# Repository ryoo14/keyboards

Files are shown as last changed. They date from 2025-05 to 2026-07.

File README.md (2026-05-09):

# rhyn47

rhyn47 is a mechanical keyboard I designed.

It comes in three models: standard, low-profile and low-profile with trackball.

Please refer to the README file located in each keyboard's folder.

## Common Across All Models

- USB-C connectivity
- Direct-mounted RP2040 on the PCB
- 47-key ortholinear layout
- Hot-swapping switch support
- Screwless design
- Can be placed on top of a laptop (so-called “Sonshi style”)

## Standard

Standard

## Low-Profile

rhyl47

## Low-Profile with TrackBall

rhyn47-trackball

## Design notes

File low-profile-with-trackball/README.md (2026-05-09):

# rhyn47 low-profile with trackball

This is low-profile model of rhyn47 with trackball.

rhyn47-trackball

The case is the same as the [low-profile version](https://github.com/ryoo14/main/tree/rhyn47/low-profile).

It's a work in progress trackball case.

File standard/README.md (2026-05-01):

# rhyn47(Standard)

rhyn47

## Layout
https://www.keyboard-layout-editor.com/#/gists/312092b0a95833e6baeb8218b6a8bbec

## Features

### Key Layout
- **Ortholinear layout**: Clean, grid-based key arrangement
- **47-key configuration**: Compact design with 2U spacebar only option
- **Hot-swappable switches**: Compatible with hot-swap switch sockets only, allowing easy switch replacement
- **Minimal design**: No LEDs or additional features - focused on simplicity

### Design Philosophy
- **Laptop-friendly**: Designed for use on top of MacBooks and other laptops
- **Zero tilt**: No default inclination for comfortable laptop use
- **AirFeet compatible**: Built-in recesses on the bottom for Nuphy Air series AirFeet attachment
- **Shisou style typing**: Enables elevated typing position when AirFeet are installed
- **v0.3 screwless design**: Completely screwless assembly for easy maintenance and modification

## Build Guide
Please read the [article](https://ryoo.cc/blog/2025-06-20_intro_rhyn47). Since it is written in Japanese, please translate it.

## Information

### Manufacturing Notes
When ordering from JLC3DP:
- **Warning alerts**: Several warnings may appear during the ordering process
- **Warping concerns**: Engineers have raised concerns about significant warping when printing the case

When I placed my order, I received the above warnings but accepted the risks and proceeded with manufacturing. The resulting product had no issues.

However, if you decide to place an order, please do so at your own risk and responsibility.

### License Notice
**Important**: The case STEP files were created using the free version of Autodesk Fusion 360, which restricts commercial use. Please use these files for personal use only.

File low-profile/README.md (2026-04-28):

# rhyn47(low-profile)

This is low-profile model of rhyn47.

YUZU Keycaps

<br />

aluminium case

<br />

resin case

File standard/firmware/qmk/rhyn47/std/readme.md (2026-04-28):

# rhyn47

rhyn47

*A short description of the keyboard/project*

* Keyboard Maintainer: [ryoo](https://github.com/ryoo14)
* Hardware Supported: *The PCBs, controllers supported*
* Hardware Availability: *Links to where you can find this hardware*

Make example for this keyboard (after setting up your build environment):

    make rhyn47/std/v0_[123]:default

Flashing example for this keyboard:

    make rhyn47/std/v0_[123]:default:flash

See the [build environment setup](https://docs.qmk.fm/#/getting_started_build_tools) and the [make instructions](https://docs.qmk.fm/#/getting_started_make_guide) for more information. Brand new to QMK? Start with our [Complete Newbs Guide](https://docs.qmk.fm/#/newbs).

## Bootloader

Enter the bootloader in 3 ways:

* **Bootmagic reset**: Hold down the key at (0,0) in the matrix (usually the top left key or Escape) and plug in the keyboard
* **Physical reset button**: Briefly press the button on the back of the PCB - some may have pads you must short instead
* **Keycode in layout**: Press the key mapped to `QK_BOOT` if it is available

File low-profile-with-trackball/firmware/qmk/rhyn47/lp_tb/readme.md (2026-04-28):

# rhyn47 low-profile with trackball

rhyl47b

**Note: The PMW3610 driver is required when building the firmware.**

*A short description of the keyboard/project*

* Keyboard Maintainer: [ryoo](https://github.com/ryoo14)
* Hardware Supported: *The PCBs, controllers supported*
* Hardware Availability: *Links to where you can find this hardware*

Make example for this keyboard (after setting up your build environment):

    make rhyn47/lp_tb/v0_1:vial

Flashing example for this keyboard:

    make rhyn47/lp_tb/v0_1:vial:flash

See the [build environment setup](https://docs.qmk.fm/#/getting_started_build_tools) and the [make instructions](https://docs.qmk.fm/#/getting_started_make_guide) for more information. Brand new to QMK? Start with our [Complete Newbs Guide](https://docs.qmk.fm/#/newbs).

## Bootloader

Enter the bootloader in 3 ways:

* **Bootmagic reset**: Hold down the key at (0,0) in the matrix (usually the top left key or Escape) and plug in the keyboard
* **Physical reset button**: Briefly press the button on the back of the PCB - some may have pads you must short instead
* **Keycode in layout**: Press the key mapped to `QK_BOOT` if it is available

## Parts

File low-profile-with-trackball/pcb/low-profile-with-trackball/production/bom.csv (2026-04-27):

Designator | Footprint | Quantity | Value | LCSC Part #
C1, C2, C22, C23 | 0402 | 4 | 10uF | C15525
C10, C11, C12, C13, C5, C6, C7, C8, C9 | 0402 | 9 | 100n | C1525
C14 | 0805 | 1 | 10uF | C15850
C15, C16 | 0603 | 2 | 10nF | C57112
C17 | 0402 | 1 | 100nF | C1525
C18, C19, C21 | 0603 | 3 | 100nF | C14663
C20 | 0805 | 1 | 3.3uF | C7393948
C24, C25 | 0402 | 2 | 20pF | C1554
C3, C4 | 0402 | 2 | 2.2uF | C307418
D1, D10, D11, D12, D13, D14, D15, D16, D17, D18, D19, D2, D20, D21, D22, D23, D24, D25, D26, D27, D28, D29, D3, D30, D31, D32, D33, D34, D35, D36, D37, D38, D39, D4, D40, D41, D42, D43, D44, D45, D46, D47, D5, D6, D7, D8, D9 | Diode_TH_SMD | 47 | D | C81598
F2 | 1206 | 1 | fuse | C70076
J2 | USB_C_Receptacle_HRO_TYPE-C-31-M-12 | 1 | USB_C_Receptacle_USB2.0_16P | C165948
R1, R2 | 0402 | 2 | 27 | C25100
R10, R9 | 0402 | 2 | 5.1k | C25905
R11 | 0402 | 1 | 10kΩ | C25744
R12 | 0603 | 1 | 10kΩ | C25804
R13 | 0402 | 1 | 1K | C11702
R8 | 0402 | 1 | 1KΩ | C11702
SW1, SW10, SW11, SW12, SW13, SW14, SW15, SW16, SW17, SW18, SW19, SW2, SW20, SW21, SW22, SW23, SW24, SW25, SW26, SW27, SW28, SW29, SW3, SW30, SW31, SW32, SW33, SW34, SW35, SW36, SW37, SW38, SW39, SW4, SW40, SW41, SW42, SW43, SW44, SW45, SW46, SW47, SW5, SW6, SW7, SW8, SW9 | Choc_v2_Hotswap_1u | 47 | SW_PUSH
SW48 | SW_Push_1P1T_XKB_TS-1187A | 1 | boot | C318884
U1 | QFN-56-1EP_7x7mm_P0.4mm_EP3.2x3.2mm | 1 | RP2040 | C2040
U2 | W25Q16JVUXIQ_WIN | 1 | W25Q16JVUXIQ | C2843335
U3 | PMW3610DM-SUDU 16Pin | 1 | PMW3610
U4 | SOT-23-3 | 1 | XC6206P332MR | C5446
U5 | SOT-363-6_2P2X1P35_ONS | 1 | SMF05CT1G | C15879
U6 | SOT-23 | 1 | MCP1700x-180xxTT | C150796
Y1 | Crystal_SMD_3225-4Pin_3.2x2.5mm | 1 | X322512MSB4SI | C9002

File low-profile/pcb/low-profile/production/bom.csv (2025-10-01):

Designator | Footprint | Quantity | Value | LCSC Part #
C1, C2 | 0402 | 2 | 10uF | C15525
C10, C11, C12, C13, C6, C7, C8, C9 | 0402 | 8 | 100n
C17 | 0402 | 1 | 100nF | C1525
C3, C4 | 0402 | 2 | 2.2uF | C307418
C5 | 0402 | 1 | 100n | C1525
D1, D10, D11, D12, D13, D14, D15, D16, D17, D18, D19, D2, D20, D21, D22, D23, D24, D25, D26, D27, D28, D29, D3, D30, D31, D32, D33, D34, D35, D36, D37, D38, D39, D4, D40, D41, D42, D43, D44, D45, D46, D47, D5, D6, D7, D8, D9 | Diode_TH_SMD | 47 | D
F2 | 1206 | 1 | fuse | C70076
J2 | USB_C_Receptacle_HRO_TYPE-C-31-M-12 | 1 | USB_C_Receptacle_USB2.0_16P | C165948
R1, R2 | 0402 | 2 | 27 | C25190
R10, R9 | 0402 | 2 | 5.1k | C25905
R11 | 0402 | 1 | 10kΩ | C25744
R3 | 0402 | 1 | 1k
R8 | 0402 | 1 | 1KΩ | C11702
SW48 | SW_Push_1P1T_XKB_TS-1187A | 1 | boot | C318884
U1 | QFN-56-1EP_7x7mm_P0.4mm_EP3.2x3.2mm | 1 | RP2040 | C2040
U2 | W25Q16JVUXIQ_WIN | 1 | W25Q16JVUXIQ | C2843335
U4 | SOT-23-3 | 1 | XC6206P332MR | C5446
U5 | SOT-363-6_2P2X1P35_ONS | 1 | SMF05CT1G | C15879
Y2 | Resonator_SMD_Murata_CSTxExxV-3Pin_3.0x1.1mm | 1 | 12MHz | C341520

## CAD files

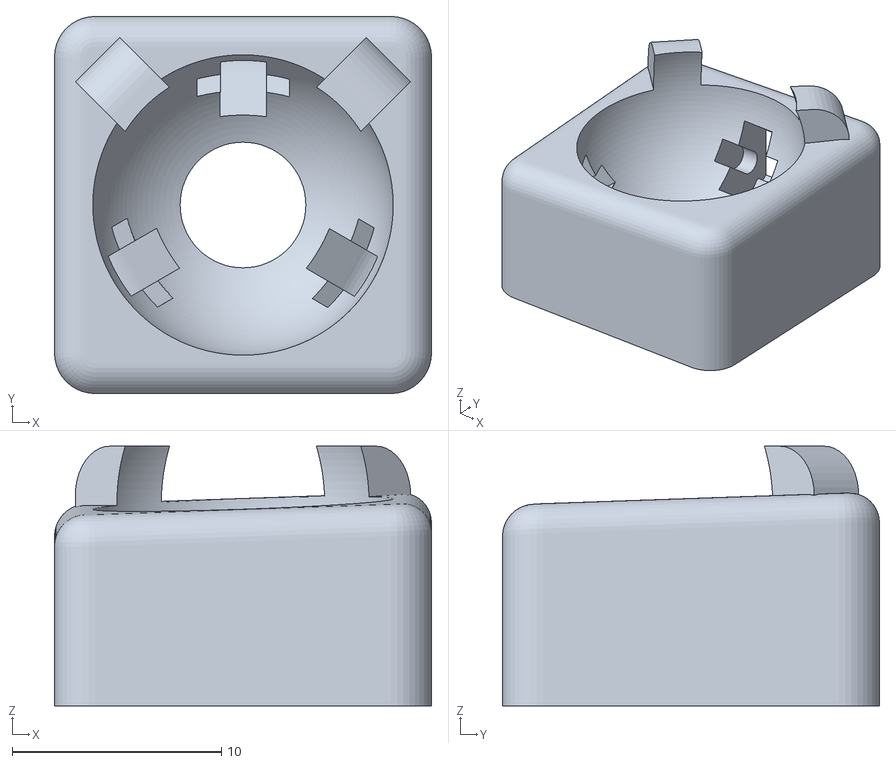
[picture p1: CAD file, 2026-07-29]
low-profile-with-trackball/case/trackball-case-v2-2.5-5.stl
18.0 x 18.0 x 12.4

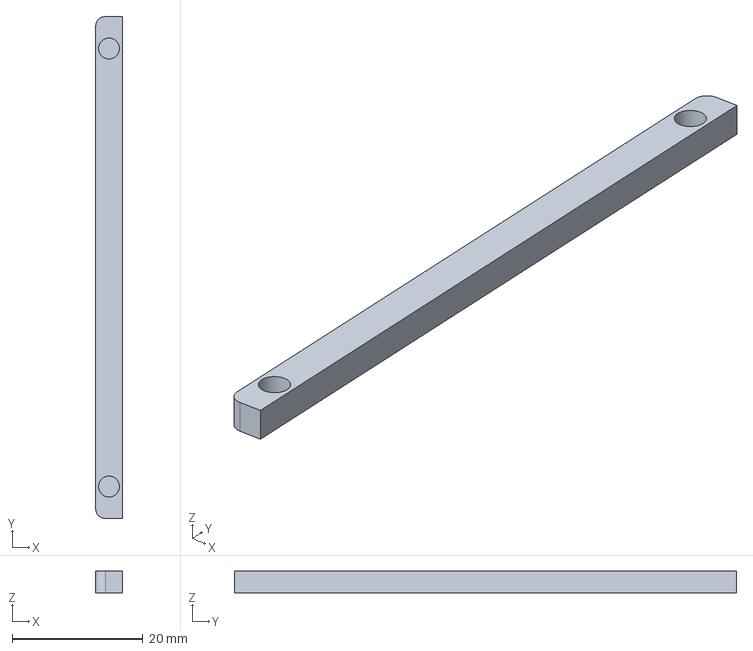
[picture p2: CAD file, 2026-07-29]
low-profile/case/low-profile-sidebar-v2.FCStd
4.10 x 76.9 x 3.30 mm

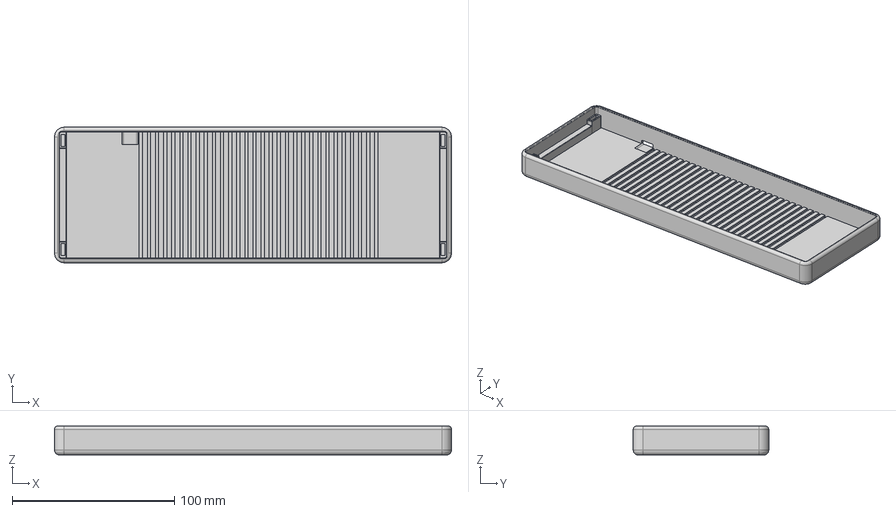
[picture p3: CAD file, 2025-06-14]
standard/case/standard-case-onboard-mcu.step
244.5 x 83.5 x 17.8 mm

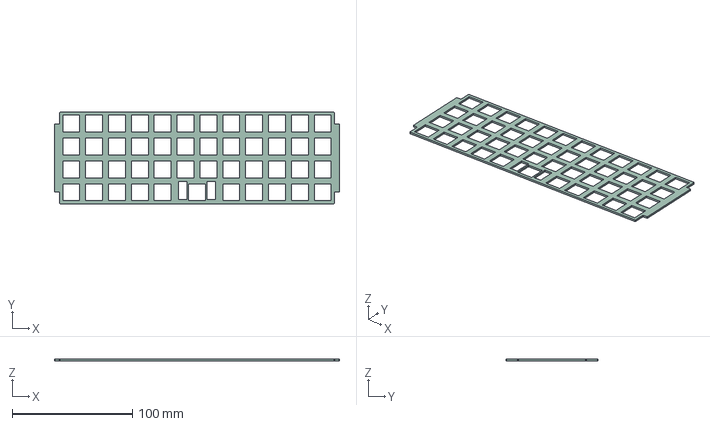
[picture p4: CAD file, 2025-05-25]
standard/plate/3dp_case/switch_plate/switch_plate.step
237.5 x 76.5 x 1.51 mm

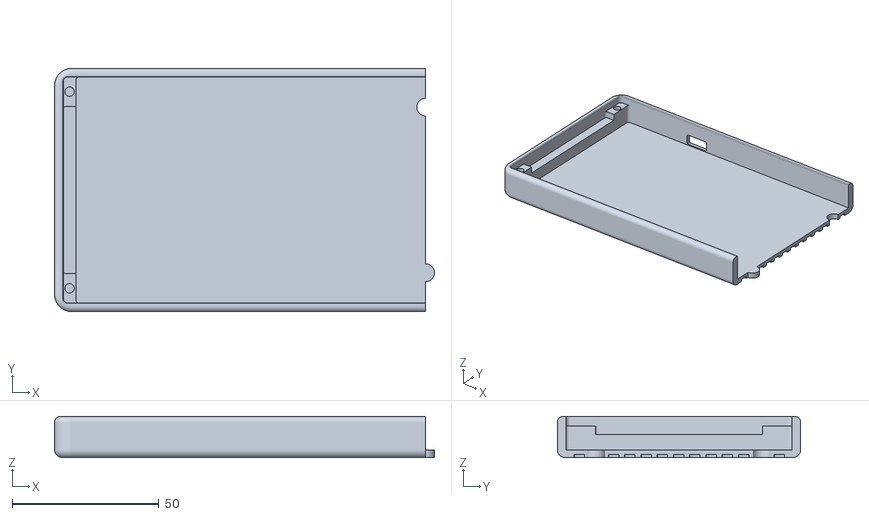
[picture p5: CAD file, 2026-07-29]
low-profile/case/low-profile-case-cut-left.stl
129.7 x 83.1 x 14.0

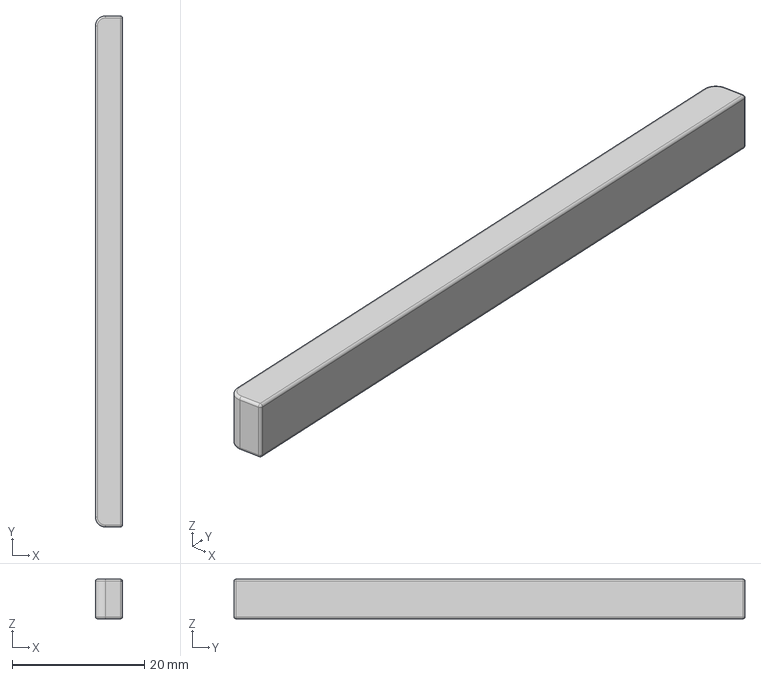
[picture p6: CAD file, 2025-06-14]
standard/case/sidebar-mini.step
4.10 x 77.3 x 6.00 mm

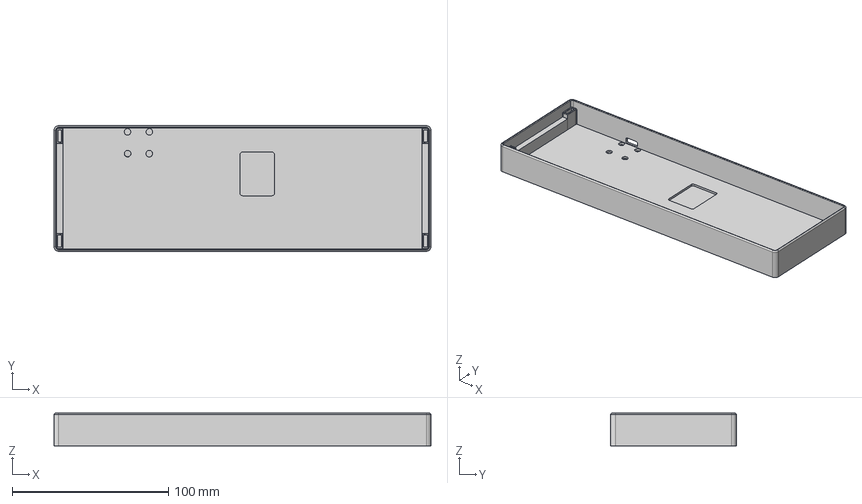
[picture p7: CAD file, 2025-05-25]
standard/plate/3dp_case/switch_plate/rhyn-oc47-top_plate_3dcasev2.step
241.5 x 80.5 x 21.0 mm

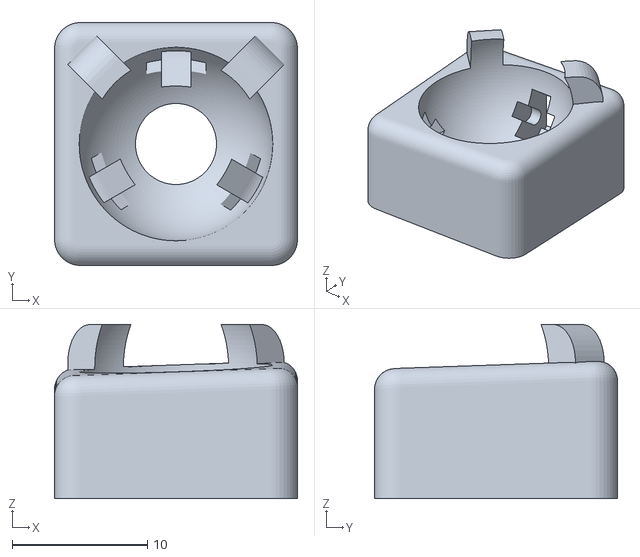
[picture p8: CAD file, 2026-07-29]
low-profile-with-trackball/case/trackball-case-v2-2.5.stl
18.0 x 18.0 x 12.9

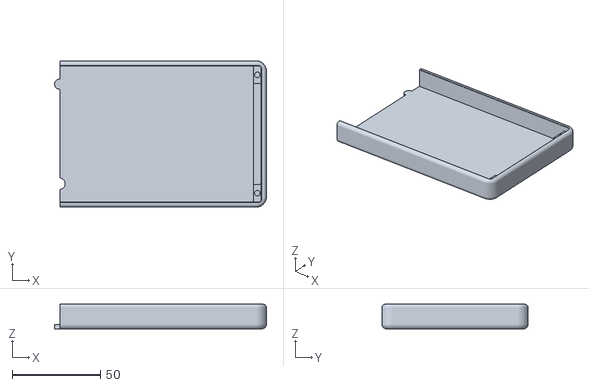
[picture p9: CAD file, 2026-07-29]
low-profile/case/low-profile-case-cut-right.stl
120.3 x 83.1 x 14.0

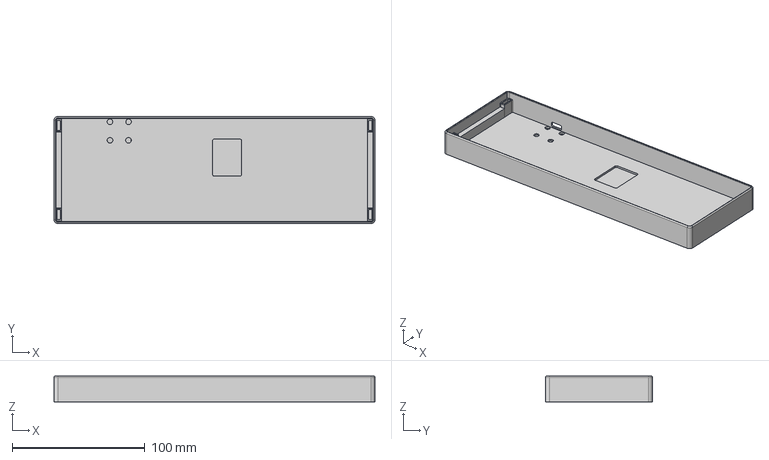
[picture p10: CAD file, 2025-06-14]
standard/case/standard-case-rp2040-tiny.step
241.5 x 80.5 x 19.5 mm

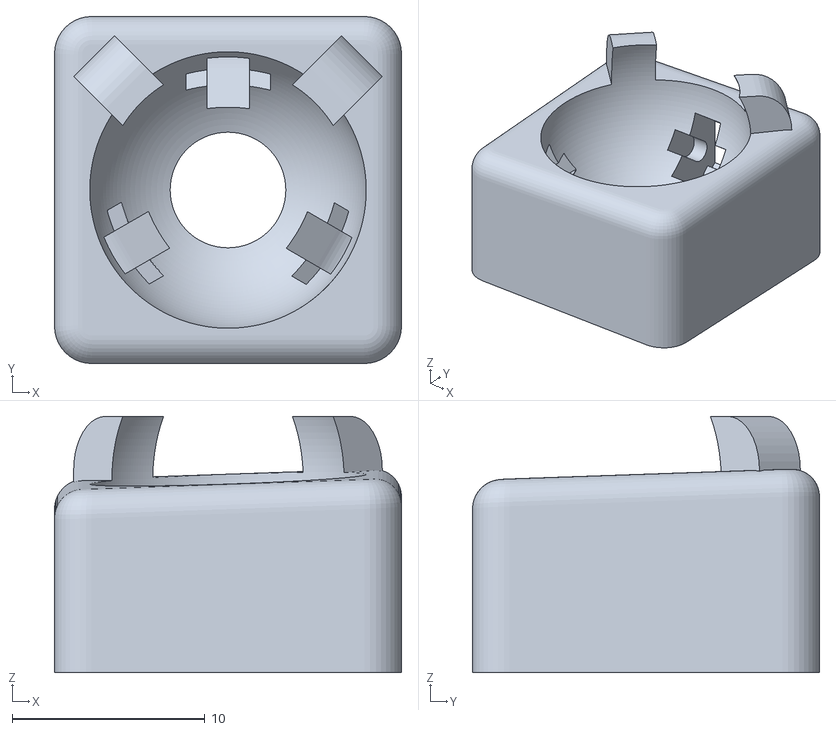
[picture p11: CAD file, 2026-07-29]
low-profile-with-trackball/case/trackball-case-v2-2.9.stl
18.0 x 18.0 x 13.3

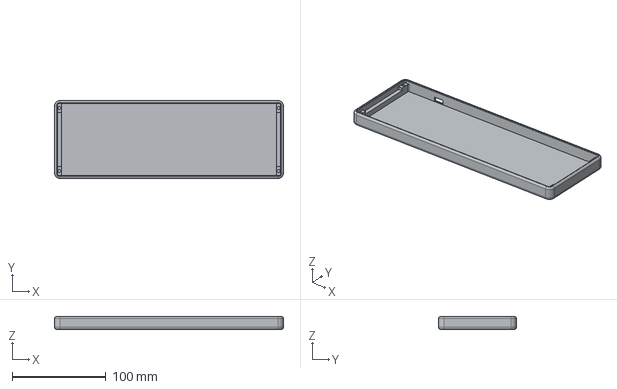
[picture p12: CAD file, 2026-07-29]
low-profile/case/low-profile-case-v0.4.step
244.1 x 83.1 x 14.0 mm

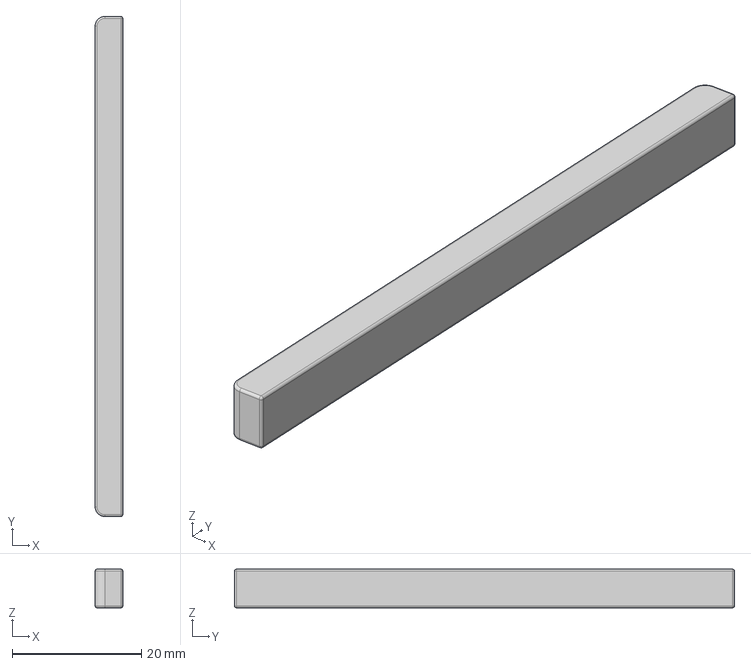
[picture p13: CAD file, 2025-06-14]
standard/case/sidebar.step
4.30 x 77.5 x 6.00 mm

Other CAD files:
low-profile-with-trackball/case/trackball-case-v2-2.6-5.stl
low-profile-with-trackball/case/trackball-case-v2-2.7.stl
low-profile/case/low-profile-case-cut.FCStd
low-profile-with-trackball/case/trackball-case-v2-2.6.stl
low-profile/case/low-profile-case.FCStd
low-profile-with-trackball/case/trackball-case-v2-2.5.blend
low-profile-with-trackball/case/trackball-case-v2-2.6.blend
low-profile-with-trackball/case/trackball-case-v2-2.7.blend
low-profile-with-trackball/case/trackball-case-v2-2.8.blend
low-profile-with-trackball/case/trackball-case-v2-2.8.stl
low-profile-with-trackball/case/trackball-case-v2-2.9.blend
low-profile/case/low-profile-case-v0.3.step
low-profile/case/low-profile-sidebar.FCStd
low-profile/case/low-profile-sidebar.step
low-profile/case/rhyl47_pcb.step

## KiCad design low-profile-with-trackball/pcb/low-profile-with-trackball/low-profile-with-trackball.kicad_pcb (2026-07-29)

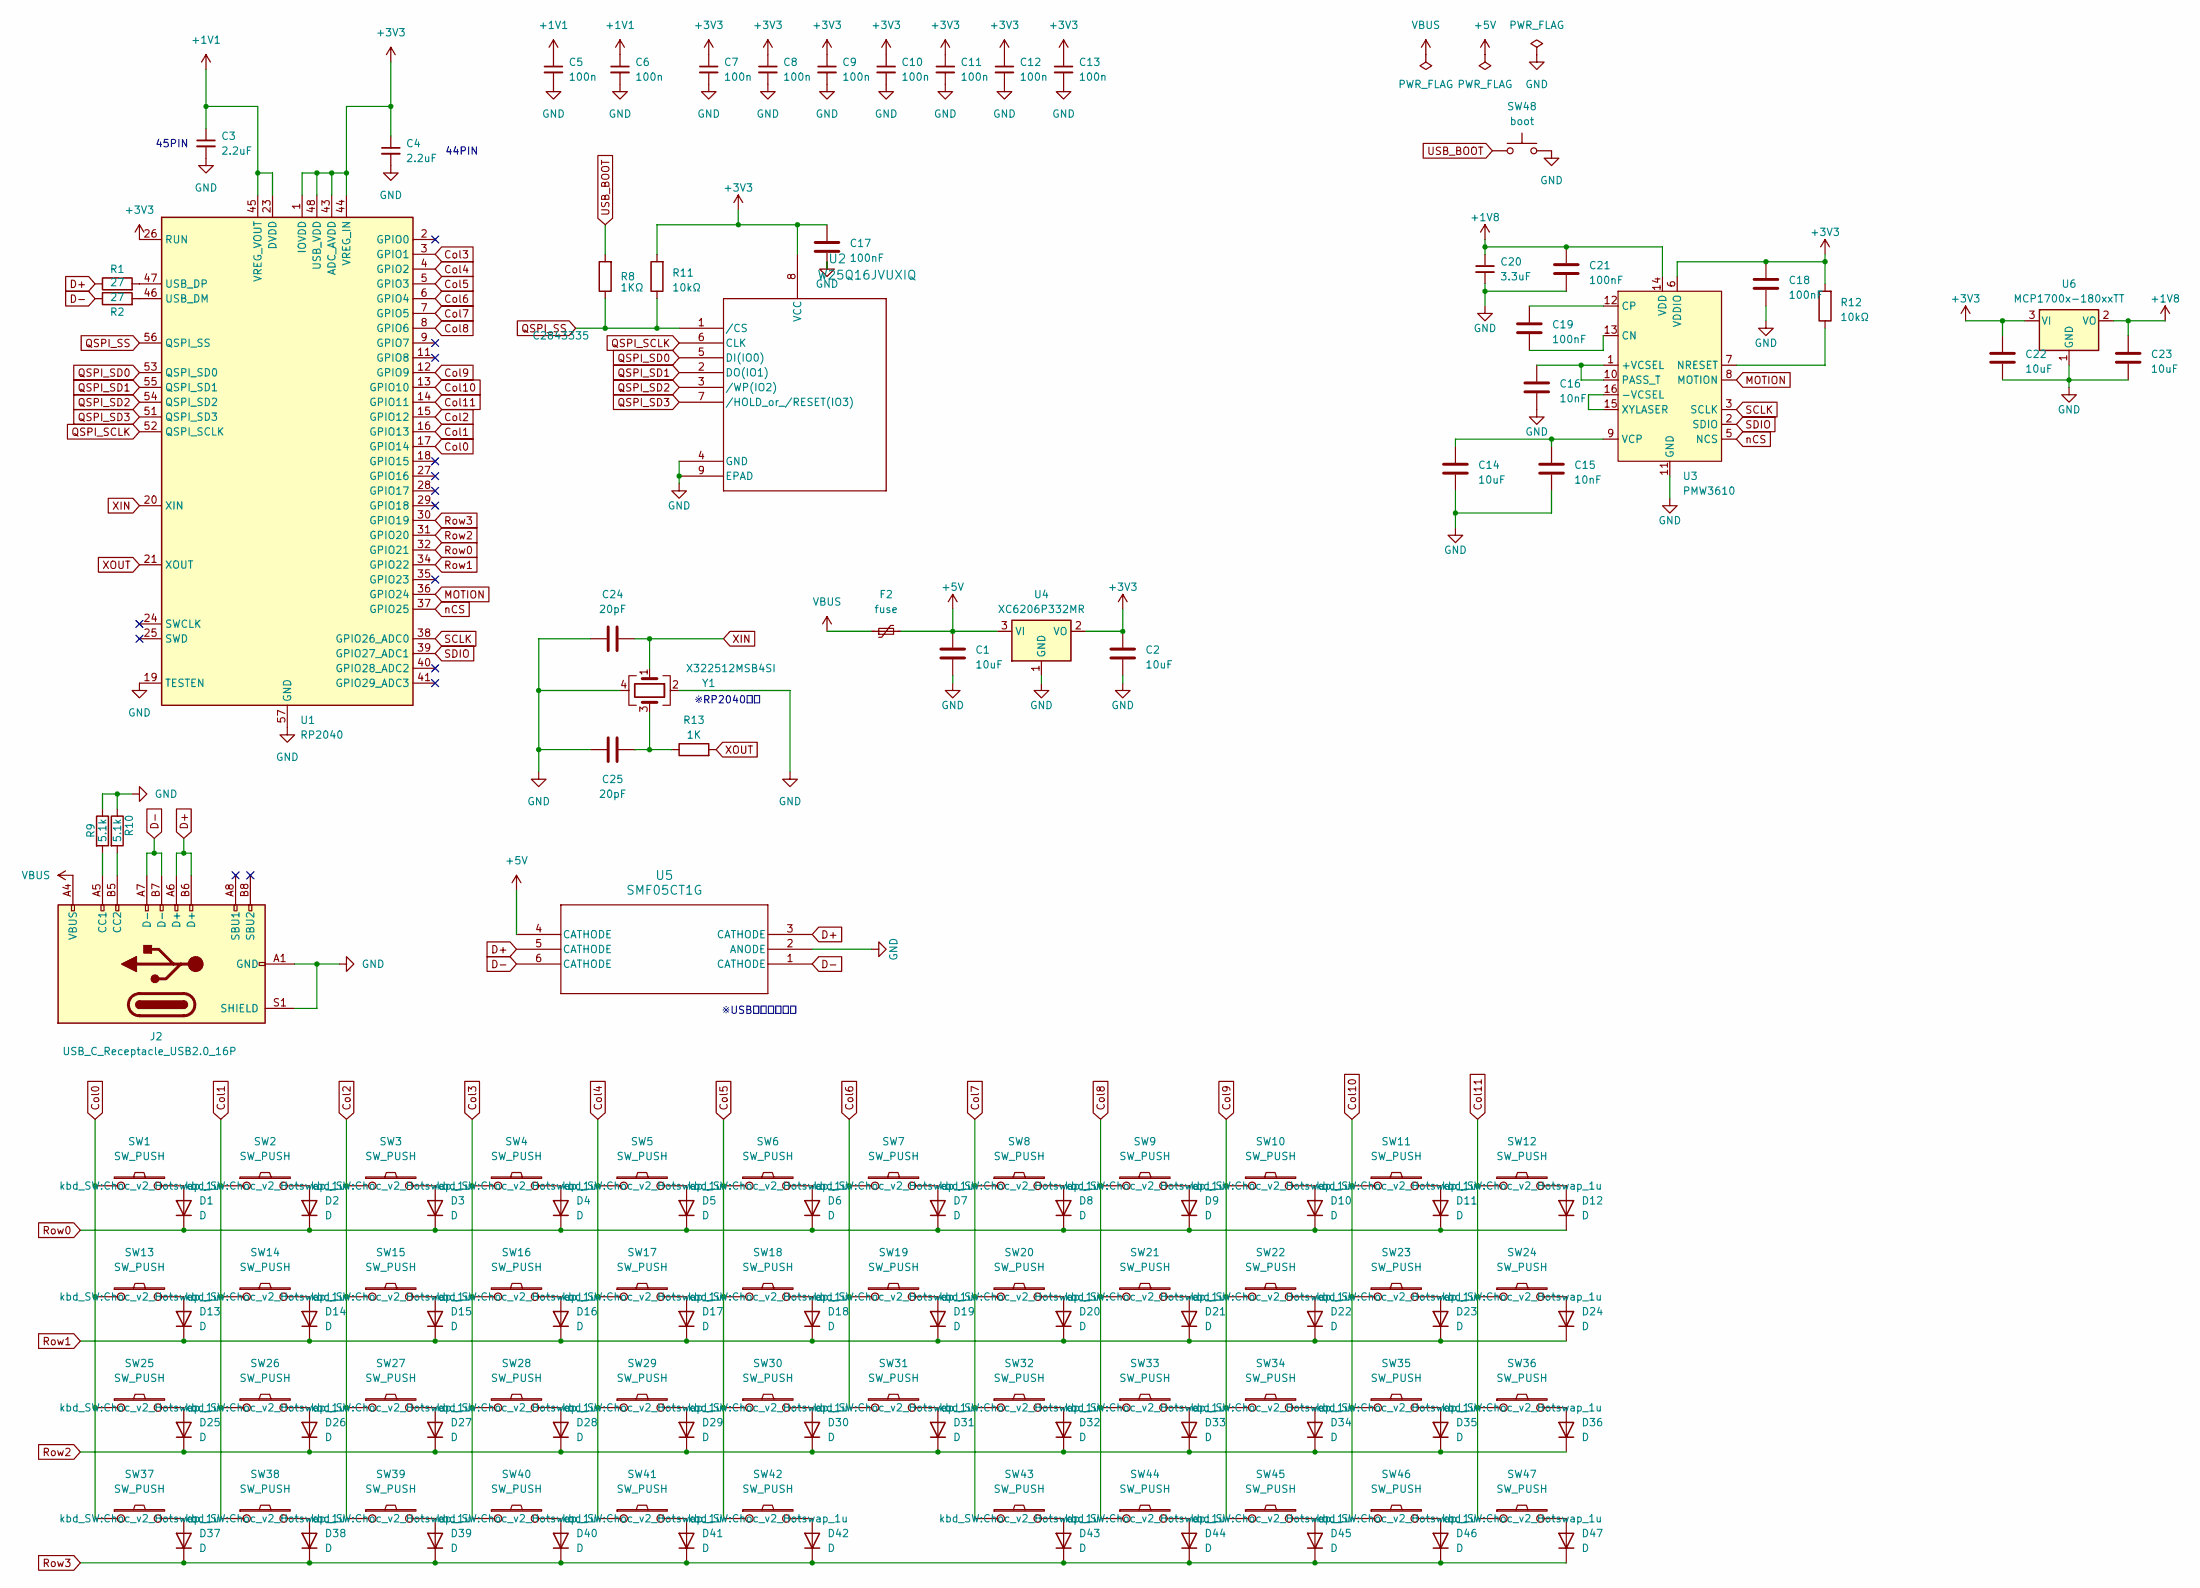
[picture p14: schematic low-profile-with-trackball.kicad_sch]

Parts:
C1, C2, C22, C23: 10uF; C_0402_1005Metric; JLCPCB Part # C15525
C3, C4: 2.2uF; C_0402_1005Metric; JLCPCB Part # C307418
C5, C6, C7, C8, C9, C10, C11, C12, C13: 100n; C_0402_1005Metric; JLCPCB Part # C1525
C14: 10uF; C_0805_2012Metric; JLCPCB Part # C15850
C15, C16: 10nF; C_0603_1608Metric; JLCPCB Part # C57112
C17: 100nF; C_0402_1005Metric; JLCPCB Part # C1525
C18, C19, C21: 100nF; C_0603_1608Metric; JLCPCB Part # C14663
C20: 3.3uF; C_0805_2012Metric; JLCPCB Part # C7393948
C24, C25: 20pF; C_0402_1005Metric; JLCPCB Part # C1554
D1, D2, D3, D4, D5, D6, D7, D8, D9, D10, D11, D12, D13, D14, D15, D16, D17, D18, D19, D20, D21, D22, D23, D24, D25, D26, D27, D28, D29, D30, D31, D32, D33, D34, D35, D36, D37, D38, D39, D40, D41, D42, D43, D44, D45, D46, D47: D; Diode_TH_SMD
F2: fuse; Fuse_1206_3216Metric; JLCPCB Part # C70076
J2: USB_C_Receptacle_USB2.0_16P; USB_C_Receptacle_HRO_TYPE-C-31-M-12; JLCPCB Part # C165948
R1, R2: 27; R_0402_1005Metric; JLCPCB Part # C25100
R8: 1KΩ; R_0402_1005Metric; JLCPCB Part # C11702
R9, R10: 5.1k; R_0402_1005Metric; JLCPCB Part # C25905
R11: 10kΩ; R_0402_1005Metric; JLCPCB Part # C25744
R12: 10kΩ; R_0603_1608Metric; JLCPCB Part # C25804
R13: 1K; R_0402_1005Metric; JLCPCB Part # C11702
SW1, SW2, SW3, SW4, SW5, SW6, SW7, SW8, SW9, SW10, SW11, SW12, SW13, SW14, SW15, SW16, SW17, SW18, SW19, SW20, SW21, SW22, SW23, SW24, SW25, SW26, SW27, SW28, SW29, SW30, SW31, SW32, SW33, SW34, SW35, SW36, SW37, SW38, SW39, SW40, SW41, SW42, SW43, SW44, SW45, SW46, SW47: SW_PUSH; Choc_v2_Hotswap_1u
SW48: boot; SW_Push_1P1T_XKB_TS-1187A; JLCPCB Part # C318884
U1: RP2040; QFN-56-1EP_7x7mm_P0.4mm_EP3.2x3.2mm; JLCPCB Part # C2040
U2: W25Q16JVUXIQ; W25Q16JVUXIQ_WIN; JLCPCB Part # C2843335
U3: PMW3610; PMW3610DM-SUDU 16Pin
U4: XC6206P332MR; SOT-23-3; JLCPCB Part # C5446
U5: SMF05CT1G; SOT-363-6_2P2X1P35_ONS; JLCPCB Rotation Offset 180
U6: MCP1700x-180xxTT; SOT-23; JLCPCB Part # C150796
Y1: X322512MSB4SI; Crystal_SMD_3225-4Pin_3.2x2.5mm; JLCPCB Part # C9002

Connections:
+1V1: C3.1, C5.1, C6.1, U1.23 (DVDD), U1.45 (VREG_VOUT), U1.50 (DVDD)
+1V8: C20.1, C21.1, C23.1, U3.14 (VDD), U6.2 (VO)
+3V3: C2.1, C4.1, C7.1, C8.1, C9.1, C10.1, C11.1, C12.1, C13.1, C17.1, C18.1, C22.1, R11.2, R12.2, U1.1 (IOVDD), U1.10 (IOVDD), U1.22 (IOVDD), U1.26 (RUN), U1.33 (IOVDD), U1.42 (IOVDD), U1.43 (ADC_AVDD), U1.44 (VREG_IN), U1.48 (USB_VDD), U1.49 (IOVDD), U2.8 (VCC), U3.6 (VDDIO), U4.2 (VO), U6.3 (VI)
+5V: C1.1, F2.2, U4.3 (VI), U5.4 (CATHODE)
Col0: SW1.1, SW13.1, SW25.1, SW37.1, U1.17 (GPIO14)
Col1: SW2.1, SW14.1, SW26.1, SW38.1, U1.16 (GPIO13)
Col2: SW3.1, SW15.1, SW27.1, SW39.1, U1.15 (GPIO12)
Col3: SW4.1, SW16.1, SW28.1, SW40.1, U1.3 (GPIO1)
Col4: SW5.1, SW17.1, SW29.1, SW41.1, U1.4 (GPIO2)
Col5: SW6.1, SW18.1, SW30.1, SW42.1, U1.5 (GPIO3)
Col6: SW7.1, SW19.1, SW31.1, U1.6 (GPIO4)
Col7: SW8.1, SW20.1, SW32.1, SW43.1, U1.7 (GPIO5)
Col8: SW9.1, SW21.1, SW33.1, SW44.1, U1.8 (GPIO6)
Col9: SW10.1, SW22.1, SW34.1, SW45.1, U1.12 (GPIO9)
Col10: SW11.1, SW23.1, SW35.1, SW46.1, U1.13 (GPIO10)
Col11: SW12.1, SW24.1, SW36.1, SW47.1, U1.14 (GPIO11)
D+: J2.A6 (D+), J2.B6 (D+), R1.1, U5.3 (CATHODE), U5.5 (CATHODE)
D-: J2.A7 (D-), J2.B7 (D-), R2.1, U5.1 (CATHODE), U5.6 (CATHODE)
GND: C1.2, C2.2, C3.2, C4.2, C5.2, C6.2, C7.2, C8.2, C9.2, C10.2, C11.2, C12.2, C13.2, C14.2, C15.2, C16.2, C17.2, C18.2, C20.2, C21.2, C22.2, C23.2, C24.1, C25.1, J2.A1 (GND), J2.A12 (GND), J2.B1 (GND), J2.B12 (GND), J2.S1 (SHIELD), R9.1, R10.1, SW48.2, U1.19 (TESTEN), U1.57 (GND), U2.4 (GND), U2.9 (EPAD), U3.11 (GND), U4.1 (GND), U5.2 (ANODE), U6.1 (GND), Y1.2, Y1.4
MOTION: U1.36 (GPIO24), U3.8 (MOTION)
unnamed: C25.2, R13.1, Y1.3
unnamed: D1.2 (A), SW1.2
unnamed: D2.2 (A), SW2.2
unnamed: D3.2 (A), SW3.2
unnamed: D4.2 (A), SW4.2
unnamed: D5.2 (A), SW5.2
unnamed: D6.2 (A), SW6.2
unnamed: D7.2 (A), SW7.2
unnamed: D8.2 (A), SW8.2
unnamed: D9.2 (A), SW9.2
unnamed: D10.2 (A), SW10.2
unnamed: D11.2 (A), SW11.2
unnamed: D12.2 (A), SW12.2
unnamed: D13.2 (A), SW13.2
unnamed: D14.2 (A), SW14.2
unnamed: D15.2 (A), SW15.2
unnamed: D16.2 (A), SW16.2
unnamed: D17.2 (A), SW17.2
unnamed: D18.2 (A), SW18.2
unnamed: D19.2 (A), SW19.2
unnamed: D20.2 (A), SW20.2
unnamed: D21.2 (A), SW21.2
unnamed: D22.2 (A), SW22.2
unnamed: D23.2 (A), SW23.2
unnamed: D24.2 (A), SW24.2
unnamed: D25.2 (A), SW25.2
unnamed: D26.2 (A), SW26.2
unnamed: D27.2 (A), SW27.2
unnamed: D28.2 (A), SW28.2
unnamed: D29.2 (A), SW29.2
unnamed: D30.2 (A), SW30.2
unnamed: D31.2 (A), SW31.2
unnamed: D32.2 (A), SW32.2
unnamed: D33.2 (A), SW33.2
unnamed: D34.2 (A), SW34.2
unnamed: D35.2 (A), SW35.2
unnamed: D36.2 (A), SW36.2
unnamed: D37.2 (A), SW37.2
unnamed: D38.2 (A), SW38.2
unnamed: D39.2 (A), SW39.2
unnamed: D40.2 (A), SW40.2
unnamed: D41.2 (A), SW41.2
unnamed: D42.2 (A), SW42.2
unnamed: D43.2 (A), SW43.2
unnamed: D44.2 (A), SW44.2
unnamed: D45.2 (A), SW45.2
unnamed: D46.2 (A), SW46.2
unnamed: D47.2 (A), SW47.2
unnamed: J2.A5 (CC1), R9.2
unnamed: J2.B5 (CC2), R10.2
unnamed: R2.2, U1.46 (USB_DM)
unnamed: R1.2, U1.47 (USB_DP)
unnamed: C16.1, U3.1 (+VCSEL), U3.10 (PASS_T)
unnamed: U3.15 (XYLASER), U3.16 (-VCSEL)
unnamed: C19.2, U3.13 (CN)
unnamed: C19.1, U3.12 (CP)
unnamed: R12.1, U3.7 (NRESET)
unnamed: C14.1, C15.1, U3.9 (VCP)
QSPI_SCLK: U1.52 (QSPI_SCLK), U2.6 (CLK)
QSPI_SD0: U1.53 (QSPI_SD0), U2.5 (DI(IO0))
QSPI_SD1: U1.55 (QSPI_SD1), U2.2 (DO(IO1))
QSPI_SD2: U1.54 (QSPI_SD2), U2.3 (/WP(IO2))
QSPI_SD3: U1.51 (QSPI_SD3), U2.7 (/HOLD_or_/RESET(IO3))
QSPI_SS: R8.1, R11.1, U1.56 (QSPI_SS), U2.1 (/CS)
Row0: D1.1 (K), D2.1 (K), D3.1 (K), D4.1 (K), D5.1 (K), D6.1 (K), D7.1 (K), D8.1 (K), D9.1 (K), D10.1 (K), D11.1 (K), D12.1 (K), U1.32 (GPIO21)
Row1: D13.1 (K), D14.1 (K), D15.1 (K), D16.1 (K), D17.1 (K), D18.1 (K), D19.1 (K), D20.1 (K), D21.1 (K), D22.1 (K), D23.1 (K), D24.1 (K), U1.34 (GPIO22)
Row2: D25.1 (K), D26.1 (K), D27.1 (K), D28.1 (K), D29.1 (K), D30.1 (K), D31.1 (K), D32.1 (K), D33.1 (K), D34.1 (K), D35.1 (K), D36.1 (K), U1.31 (GPIO20)
Row3: D37.1 (K), D38.1 (K), D39.1 (K), D40.1 (K), D41.1 (K), D42.1 (K), D43.1 (K), D44.1 (K), D45.1 (K), D46.1 (K), D47.1 (K), U1.30 (GPIO19)
SCLK: U1.38 (GPIO26_ADC0), U3.3 (SCLK)
SDIO: U1.39 (GPIO27_ADC1), U3.2 (SDIO)
USB_BOOT: R8.2, SW48.1
VBUS: F2.1, J2.A4 (VBUS), J2.A9 (VBUS), J2.B4 (VBUS), J2.B9 (VBUS)
XIN: C24.2, U1.20 (XIN), Y1.1
XOUT: R13.2, U1.21 (XOUT)
nCS: U1.37 (GPIO25), U3.5 (NCS)

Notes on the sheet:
45PIN
※USBコネクタ近傍
※RP2040近傍
44PIN

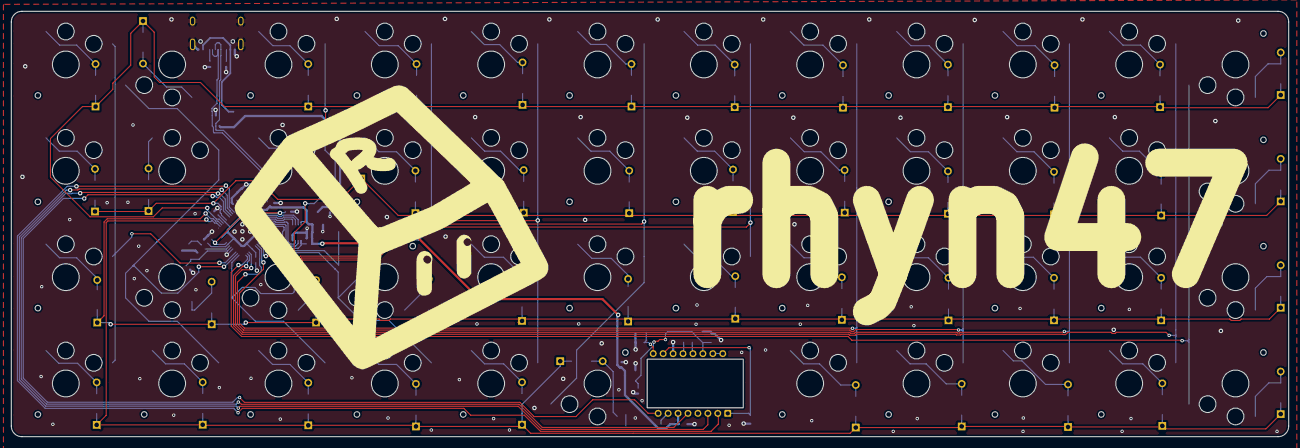
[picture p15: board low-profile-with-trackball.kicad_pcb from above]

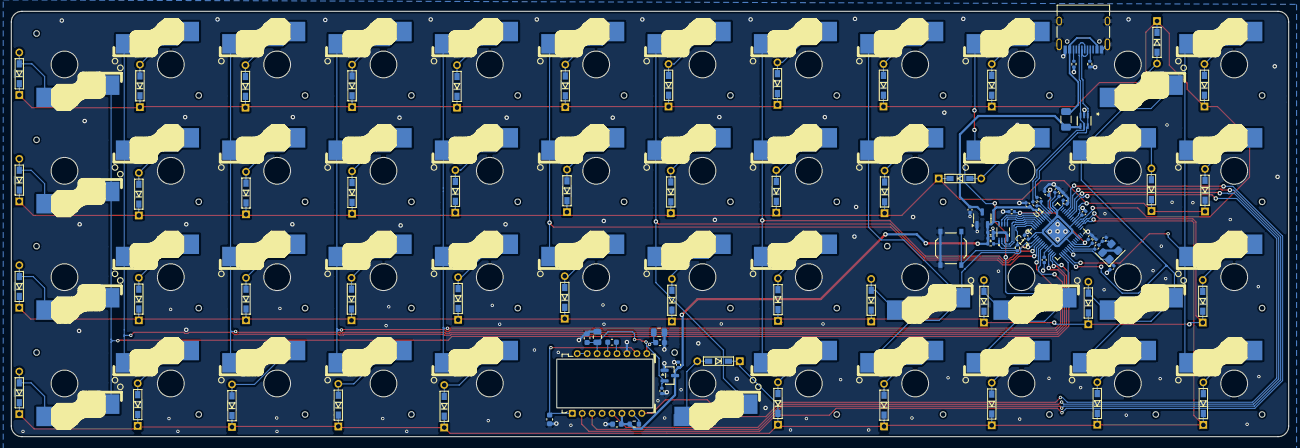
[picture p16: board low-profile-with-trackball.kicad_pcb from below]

Board: 2 copper layers, 228.8 x 76.2 mm, 137 parts (43 on the bottom side), 95 nets.

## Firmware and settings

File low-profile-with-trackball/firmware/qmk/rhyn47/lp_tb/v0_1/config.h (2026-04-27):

#define TAPPING_TERM 150
// #define POINTING_DEVICE_MOTION_PIN GP24
// #define POINTING_DEVICE_MOTION_PIN_ACTIVE_LOW
#define POINTING_DEVICE_CS_PIN GP25
#define POINTING_DEVICE_SCLK_PIN GP26
#define POINTING_DEVICE_SDIO_PIN GP27
#define POINTING_DEVICE_INVERT_Y
#define POINTING_DEVICE_AUTO_MOUSE_ENABLE

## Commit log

2025-05-05 fix: adjust to prevent the screws at the four corners from interfering with the PCB
    [bottom_plate.kicad_pcb, rhyn-oc47-top_plate.kicad_pcb]
2025-05-05 fix: fix the typo and adjust the size of the silkscreen in the bottom right corner
    [rhyn-oc47-assemble.kicad_pcb]
2025-05-06 chore: clean up routing and add edge vias
    [rhyn-oc47-assemble.kicad_pcb]
2025-05-06 fix: avoid orthogonal traces through vias
    [rhyn-oc47-assemble.kicad_pcb]
2025-05-09 feat: rewire myself
    [rhyn-oc47-assemble.dsn, rhyn-oc47-assemble.kicad_pcb, rhyn-oc47-assemble.kicad_sch]
2025-05-09 chore: gnd beta
    [rhyn-oc47-assemble.kicad_pcb]
2025-05-09 chore: for jlcpcb
    [bom.csv, positions.csv]
2025-05-09 chore: add big icon
    [bom.csv, designators.csv, positions.csv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]
2025-05-10 chore: change icons
    [rhyn-oc47-assemble.kicad_pcb]
2025-05-10 chore: etc
    [designators.csv, positions.csv, rhyn-oc47-assemble.kicad_pcb]
2025-05-10 feat: switch plate for 3d print case
2025-05-25 chore: step files for 3dcase
    [rhyn-oc47-top_plate_3dcase.step, rhyn-oc47-top_plate_3dcasev2.step]
2025-06-03 chore: lower case
    [rhyn-oc47-top_plate_3dcase_lower.step]
2025-06-03 direct mcu
    [assemble_direct.kicad_pcb, assemble_direct.kicad_sch, bom.csv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]
2025-06-04 chore refactor folder structure
    [PCB_RP2040-Tiny.kicad_pcb, PCB_RP2040-Tiny.kicad_sch, PCB_RP2040_Direct.kicad_pcb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]
2025-06-14 chore: add parts number for jlcpcb
    [PCB_RP2040_Direct.kicad_pcb]
2025-06-14 feat: add case's step files
    [rhyn47_direct_case.step, rhyn47_sidebar.step, rhyn47_sidebar_mini.step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]
2025-06-23 chore: add jlcparts number
    [bom.csv]
2025-10-01 add rhyl47
    [PCB_RP2040-Tiny.kicad_pcb, PCB_RP2040-Tiny.kicad_sch, PCB_RP2040_Direct.kicad_pcb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]
2025-10-18 generate vial id and change diode direction
2025-11-08 export pdf
    [switch_plate.kicad_pcb]
2025-11-08 update case design for aluminum cnc!
    [rhyl47-Body_v0_2.step, rhyl47-Body_v0_3.step, rhyl47.FCStd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]
2026-04-27 new keyboard based on rhyl47 with track ball
    [bom.csv, designators.csv, positions.csv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]
2026-04-28 remove title
    [PCB_RP2040_Direct.kicad_pcb, rhyl47_pcb.kicad_pcb, rhyn-oc47-top_plate_3dcasev2.step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]
2026-04-28 rename keyboards
    [PCB_RP2040-OnBoard.kicad_pcb, PCB_RP2040-OnBoard.kicad_sch, PCB_RP2040-Tiny.kicad_pcb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]
2026-05-01 add trackball case data
    [trackball-case.blend, trackball-case.stl]
2026-05-02 only save
    [trackball-case.blend]
2026-05-02 remove mask
    [switch_plate_with_trackball-B_Cu.gbl, switch_plate_with_trackball-B_Mask.gbs, switch_plate_with_trackball-B_Silkscreen.gbo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]
2026-05-04 remove unneed mod
    [switch_plate_with_trackball.kicad_pcb]
2026-05-09 update non-conductive zone pattern
    [switch_plate_with_trackball.kicad_pcb]
2026-05-09 remove production files
    [switch_plate_with_trackball-B_Cu.gbl, switch_plate_with_trackball-B_Mask.gbs, switch_plate_with_trackball-B_Silkscreen.gbo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]
2026-06-13 make the hole for the magnet 1mm shallower
    [low-profile-case.FCStd]
2026-07-29 split wireless rhyn47
    [daughter.kicad_pcb, daughter.kicad_sch, normal.kicad_pcb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]
2026-07-29 add trackball base and etc
    [low-profile-case-cut-left.stl, low-profile-case-cut-right.stl, low-profile-case-cut.FCStd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]
2026-08-09 chore: migrate another repository
    [daughter.kicad_pcb, daughter.kicad_sch, normal.kicad_pcb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]
